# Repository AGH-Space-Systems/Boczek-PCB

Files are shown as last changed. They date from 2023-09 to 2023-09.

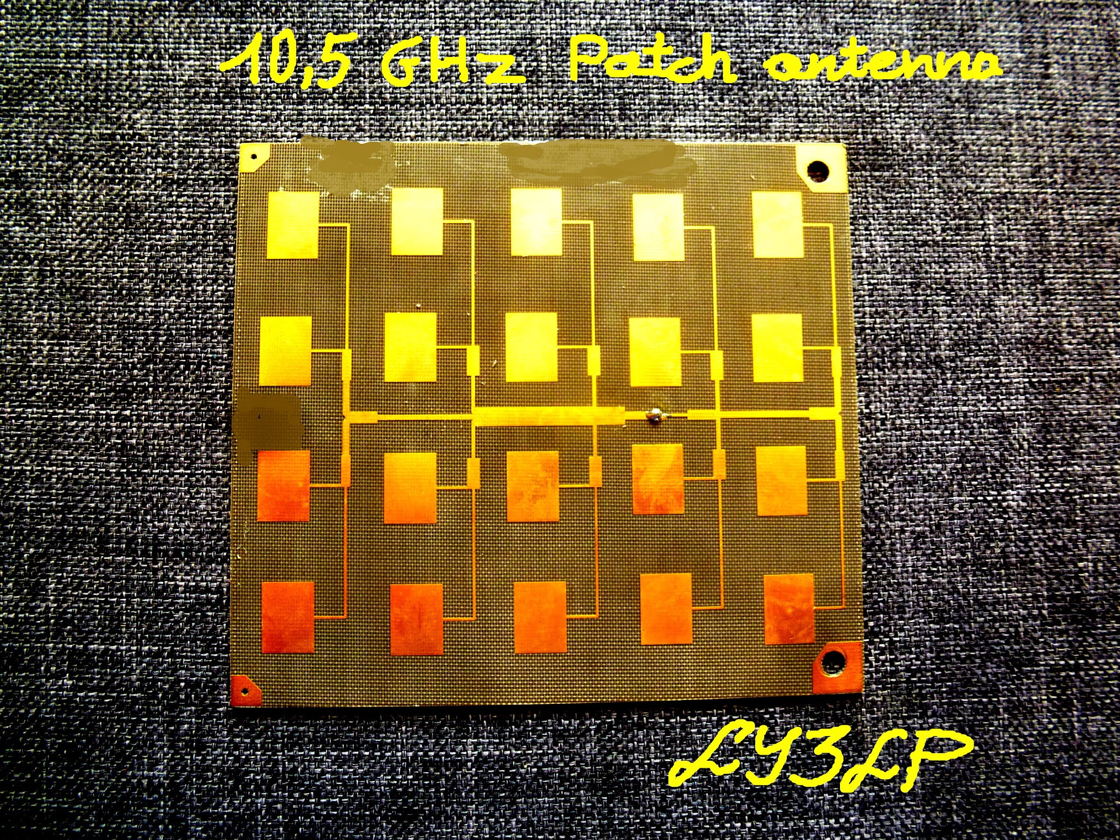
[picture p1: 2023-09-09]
ww.JPG

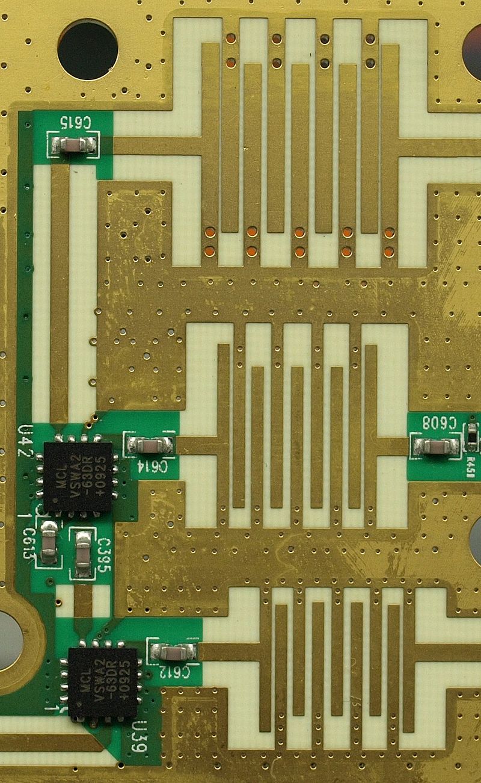
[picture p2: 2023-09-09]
Interdigital_Filter.jpg

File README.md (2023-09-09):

# Boczek-PCB
 5.8 GHz 1 W radio beacon that fits on a Li-Ion battery holder
Place libaries from "project specific libaries" in your libaries folder.
AlexRF has the filter, SamacSys_Parts the ICs.

RF PA:
https://www.mouser.pl/ProductDetail/Qorvo/RFPA5542BTR13?qs=u4fy%2FsgLU9OIcUWfOD%252Bf6g%3D%3D

3.3V LDO
https://www.mouser.pl/ProductDetail/Microchip-Technology/MIC94310-SYM5-TR?qs=U6T8BxXiZAWNaMNWfdoYvQ%3D%3D

2.2 2.5 75 3.2 × 2.5 × 1.2 HMME32251B--2R2MS CYNTEC
Coils
Have to handle 2.5A of peak switch current!
https://www.mouser.pl/ProductDetail/Laird-Performance-Materials/TYS40304R7M-10?qs=cCJXSq33DME5rIwYhom2LA%3D%3D

https://www.mouser.pl/datasheet/2/597/lps4018-270702.pdf

PCB (very important for the stripline filter to work!)
JLC04161H-7628 Stackup

BOM comming soon...

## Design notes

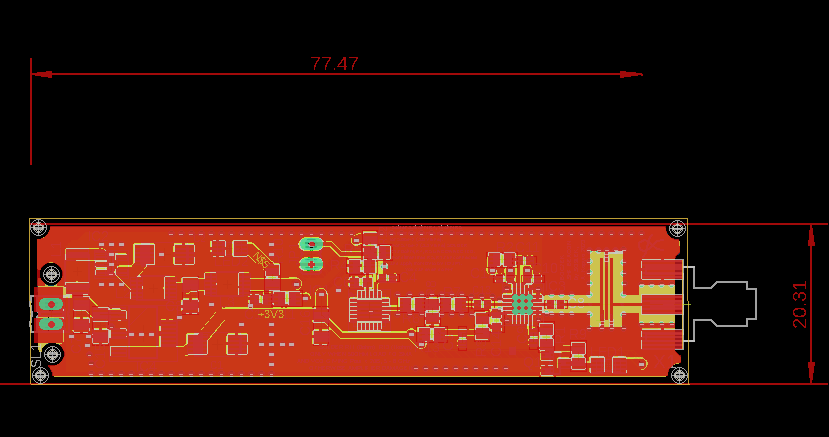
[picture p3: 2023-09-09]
board.png

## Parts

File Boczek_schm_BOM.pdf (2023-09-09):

Boczek_schm_BOM

Strona 1

Order QTY | Board QTY | Order Sub-total | Unit Price | Part | Value
10 | 1 | 26,00 zł | 2,60 zł | C1 | 4.7uF 25V 2 ohms ESR (ok enough?)
10 | 1 | 18,80 zł | 1,88 zł | C2 | 22uF 16V 1 ohm ESR (ok?)
10 | 1 | 2,80 zł | 0,28 zł | C3 | 47nF
20 | 4 | 7,04 zł | 0,35 zł | C4 C8 C9 C13 | 10pF
10 | 3 | 5,87 zł | 0,59 zł | C6 C14 C17 | 1nF
10 | 3 | 2,85 zł | 0,29 zł | C7 C15 C16 | 100nF
10 | 4 | 4,45 zł | 0,45 zł | C5 C10 C11 C12 | 2.2uF
2 | 1 | 187,08 zł | 93,54 zł | IC1 | HMC431LP4ETR
4 | 1 | 8,32 zł | 2,08 zł | IC2 | TPS613222ADBVR
3 | 1 | 43,26 zł | 14,42 zł | IC3 | RFPA5542BTR13
2 | 1 | 7,28 zł | 3,64 zł | IC4 | MCP1826S-3302E_DB
0 | 1 | 0,00 zł | 0,00 zł | JP1
10 | 1 | 20,40 zł | 2,04 zł | L1 | 2.2uH
10 | 2 | 20,40 zł | 2,04 zł | L2 L3 | 4.7uH
4 | 1 | 5,28 zł | 1,32 zł | LED1 | Amber 20mA
4 | 1 | 3,68 zł | 0,92 zł | LED2 | Green 20mA
5 | 1 | 3,41 zł | 0,68 zł | Q1 | BC847A
10 | 1 | 0,67 zł | 0,07 zł | R1 | 10k
20 | 3 | 1,60 zł | 0,08 zł | R2 R11 R12 | 0
20 | 4 | 1,34 zł | 0,07 zł | R3 R5 R10 R13 | 1k
10 | 1 | 0,40 zł | 0,04 zł | R4 | 3.3k*
10 | 1 | 0,40 zł | 0,04 zł | R6 R7 | 10
10 | 1 | 0,40 zł | 0,04 zł | R8 | 100
10 | 1 | 0,40 zł | 0,04 zł | R9 | 100k
2 | 1 | 22,34 zł | 11,17 zł | SL1 | please use 3500 mAh batts If you want 4h battery life
2 | 1 | 19,14 zł | 9,57 zł | X1 | 50 ohm SMA female pcb edge mount
| | 0,00 zł
2 | 1 | 60,00 zł | 30,00 zł | | 1.6 mm thickness
473,61 zł | = | PLN
for | 2 | devices | plus shipping
for | 1 | device: | 236,80 zł
| Gross: Total

waga | 50g | 0,05 | 4 736,09 zł /kg

Device | Package
CPOL-EUSMCE | SMC_C
CPOL-EUSMCE | SMC_C
C-EUC1206 | C1206
C-EUC0603 | C0603
C-EUC0603 | C0603
C-EUC1206 | C1206
C-EUC0402 | C0402
HMC431LP4ETR | QFN50P400X400X100-25N
TPS613222ADBVR | SOT95P280X145-5N
RFPA5542BTR13 | QFN50P400X400X85-21N
MCP1826S-3302E_DB | SOT230P700X180-4N
JP1E | JP1
SM-NE45 | SM-NE45
Converter Power Inductor | 4mm x 3mm x 4mm
LEDSMT1206 | 1206
LEDSMT1206 | 1206
BC847 | SOT23
R-EU_R0805 | R0805
R-EU_R0805 | R0805
R-EU_R0805 | R0805
R-EU_R0805 | R0805
R-EU_R0805 | R0805
R-EU_R0805 | R0805
R-EU_R0805 | R0805
18650 holder
SMA-142-0701-871/876 | CON-SMA-EDGE
JLC04161H-7628 Stackup | PCB

Description | MANUFACTURER_NAME
POLARIZED CAPACITOR, European symbol | Vishay / Sprauge
POLARIZED CAPACITOR, European symbol | KYOCERA AVX
CAPACITOR, European symbol | KEMET
CAPACITOR, European symbol | Walsin
CAPACITOR, European symbol | Wurth Elektronik
CAPACITOR, European symbol | KYOCERA AVX
CAPACITOR, European symbol | YAGEO
VCO Oscillators VCO SMT w/Buffer amp, 5.5 – 6.1 GHz | Analog Devices
6-uA Quiescent Current, 1.8-A Switch Current Boost Converter | Texas Instruments
RF Amplifier 5GHZ Discrete PA | Qorvo
LDO Regulator 1A 3.3V SOT223-3 MCP1826S-3302E/DB, Low Dropout Microchip
JUMPER
INDUCTOR | Bourns
INDUCTOR | Laird Performance Materials
LED | Lite-On
LED | Wurth Elektronik
NPN TRANSISTOR | onsemi
RESISTOR, European symbol | YAGEO
RESISTOR, European symbol | Vishay / Dale
RESISTOR, European symbol | Walsin
RESISTOR, European symbol | Walsin
RESISTOR, European symbol | Walsin
RESISTOR, European symbol | Walsin
RESISTOR, European symbol | Walsin
Cylindrical Battery Contacts, Clips, Holders & Springs 18650 P | Keystone Electronics
SMA 50 Ohm End Launch Jack Receptacle - Round Contact | 114SMAFRA.YC

Board Stackup

MANUFACTURER_PART_NUMBER | MOUSER_PART_NUMBER
293D475X9025C2TE3 | 74-293D475X9025C2TE3
TAJC226M016RNJ | 581-TAJC226M016R
C1206C473K5RACTU | 80-C1206C473K5R
RF15N100J250CT | 791-RF15N100J250CT
885382206005 | 710-885382206005
KGM31BR71H104KT | 581-KGM31BR71H104KT
CC0402KRX5R8B225 | 603-CC0402KRX5R8B225
HMC431LP4ETR | 584-HMC431LP4ETR
TPS613222ADBVR | 595-TPS613222ADBVR
RFPA5542BTR13 | 772-RFPA5542BTR13
MCP1826S-3302E/DB | 579-MCP1826S-3302EDB
SRP3212A-2R2M | 652-SRP3212A-2R2M
TYS40304R7M-10 | 875-TYS40304R7M-10
LTST-C150AKT | 859-LTST-C150AKT
150120VS75000 | 710-150120VS75000
BC847AWT1G | 863-BC847AWT1G
AC0805JR-0710KL | 603-AC0805JR-0710KL
CRCW08050000Z0EAC | 71-CRCW08050000Z0EAC
WR08X1001FTL | 791-WR08X1001FTL
WR08X332JTL | 791-WR08X332JTL
WR08X100JTL | 791-WR08X100JTL
WR08X101JTL | 791-WR08X101JTL
791-WR08X104JTL | WR08X104JTL
1043 534-1043
CON-SMA-EDGE | 114SMAFRA.YC

`

https://www.mouser.co.uk/ProductDetail/Qorvo/RFPA5542BTR13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 -

https://www.mouser.pl/ProductDetail/Vishay-Sprague/293D475X9025C2TE3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

https://www.mouser.pl/ProductDetail/Walsin/RF15N100J250CT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

https://www.mouser.pl/ProductDetail/Wurth-Elektronik/885382206005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

https://www.mouser.pl/ProductDetail/KYOCERA-AVX/KGM31BR71H104KT?qs=Jm2GQyTW%2FbjhvPjYj1wIYA%3D%3D

https://www.mouser.pl/ProductDetail/YAGEO/CC0402KRX5R8BB225?qs=0lQeLiL1qyYyJhAVzXjbiw%3D%3D

https://www.mouser.pl/ProductDetail/Analog-Devices/HMC431LP4ETR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

https://www.mouser.pl/ProductDetail/Bourns/SRP3212A-2R2M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

https://www.mouser.pl/ProductDetail/Vishay-Dale/CRCW08050000Z0EAC?qs=E3Y5ESvWgWMnvHb9ZvShmA%3D%3D

https://www.mouser.pl/ProductDetail/Walsin/WR08X1001FTL?qs=1w%252B2sDiFrrG9QUazmDfw8A%3D%3D

https://www.mouser.pl/ProductDetail/Walsin/WR08X332-JTL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

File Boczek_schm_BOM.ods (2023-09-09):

Order QTY | Board QTY | Order Sub-total | Unit Price | Part | Value | Device | Package | Description | MANUFACTURER_NAME | MANUFACTURER_PART_NUMBER | MOUSER_PART_NUMBER | `
10 | 1 | 26,00 zł | 2,60 zł | C1 | 4.7uF 25V 2 ohms ESR (ok enough?) | CPOL-EUSMCE | SMC_C | POLARIZED CAPACITOR, European symbol | Vishay / Sprauge | 293D475X9025C2TE3 | 74-293D475X9025C2TE3 | https://www.mouser.pl/ProductDetail/Vishay-Sprague/293D475X9025C2TE3
10 | 1 | 18,80 zł | 1,88 zł | C2 | 22uF 16V 1 ohm ESR (ok?) | CPOL-EUSMCE | SMC_C | POLARIZED CAPACITOR, European symbol | KYOCERA AVX | TAJC226M016RNJ | 581-TAJC226M016R | https://www.mouser.pl/ProductDetail/KYOCERA-AVX/TAJC226M016RNJ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
10 | 1 | 2,80 zł | 0,28 zł | C3 | 47nF | C-EUC1206 | C1206 | CAPACITOR, European symbol | KEMET | C1206C473K5RACTU | 80-C1206C473K5R | https://www.mouser.pl/ProductDetail/KEMET/C1206C473K5RACTU
20 | 4 | 7,04 zł | 0,35 zł | C4 C8 C9 C13 | 10pF | C-EUC0603 | C0603 | CAPACITOR, European symbol | Walsin | RF15N100J250CT | 791-RF15N100J250CT | https://www.mouser.pl/ProductDetail/Walsin/RF15N100J250CT
10 | 3 | 5,87 zł | 0,59 zł | C6 C14 C17 | 1nF | C-EUC0603 | C0603 | CAPACITOR, European symbol | Wurth Elektronik | 885382206005 | 710-885382206005 | https://www.mouser.pl/ProductDetail/Wurth-Elektronik/885382206005
10 | 3 | 2,85 zł | 0,29 zł | C7 C15 C16 | 100nF | C-EUC1206 | C1206 | CAPACITOR, European symbol | KYOCERA AVX | KGM31BR71H104KT | 581-KGM31BR71H104KT | https://www.mouser.pl/ProductDetail/KYOCERA-AVX/KGM31BR71H104KT?qs=Jm2GQyTW%2FbjhvPjYj1wIYA%3D%3D
10 | 4 | 4,45 zł | 0,45 zł | C5 C10 C11 C12 | 2.2uF | C-EUC0402 | C0402 | CAPACITOR, European symbol | YAGEO | CC0402KRX5R8B225 | 603-CC0402KRX5R8B225 | https://www.mouser.pl/ProductDetail/YAGEO/CC0402KRX5R8BB225?qs=0lQeLiL1qyYyJhAVzXjbiw%3D%3D
2 | 1 | 187,08 zł | 93,54 zł | IC1 | HMC431LP4ETR | HMC431LP4ETR | QFN50P400X400X100-25N | VCO Oscillators VCO SMT w/Buffer amp, 5.5 – 6.1 GHz | Analog Devices | HMC431LP4ETR | 584-HMC431LP4ETR | https://www.mouser.pl/ProductDetail/Analog-Devices/HMC431LP4ETR?qs=pceeu5JH%2FH%2FRfErFx7EAsA%3D%3D
4 | 1 | 8,32 zł | 2,08 zł | IC2 | TPS613222ADBVR | TPS613222ADBVR | SOT95P280X145-5N | 6-uA Quiescent Current, 1.8-A Switch Current Boost Converter | Texas Instruments | TPS613222ADBVR | 595-TPS613222ADBVR | https://www.mouser.pl/ProductDetail/Texas-Instruments/TPS613222ADBVR?qs=W0yvOO0ixfE4d69WXsn8NQ%3D%3D
3 | 1 | 43,26 zł | 14,42 zł | IC3 | RFPA5542BTR13 | RFPA5542BTR13 | QFN50P400X400X85-21N | RF Amplifier 5GHZ Discrete PA | Qorvo | RFPA5542BTR13 | 772-RFPA5542BTR13 | https://www.mouser.co.uk/ProductDetail/Qorvo/RFPA5542BTR13?qs=u4fy%2FsgLU9OIcUWfOD%252Bf6g%3D%3D
2 | 1 | 7,28 zł | 3,64 zł | IC4 | MCP1826S-3302E_DB | MCP1826S-3302E_DB | SOT230P700X180-4N | LDO Regulator 1A 3.3V SOT223-3 MCP1826S-3302E/DB, Low Dropout Voltage Regulator, 1A, 3.3 V +/-2%, 2.3 6 Vin, 4-Pin SOT-223 | Microchip | MCP1826S-3302E/DB | 579-MCP1826S-3302EDB | https://www.mouser.co.uk/ProductDetail/Microchip-Technology-Atmel/MCP1826S-3302E-DB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
0 | 1 | 0,00 zł | 0,00 zł | JP1 |  | JP1E | JP1 | JUMPER |  |  |  | -
10 | 1 | 20,40 zł | 2,04 zł | L1 | 2.2uH | SM-NE45 | SM-NE45 | INDUCTOR | Bourns | SRP3212A-2R2M | 652-SRP3212A-2R2M | https://www.mouser.pl/ProductDetail/Bourns/SRP3212A-2R2M?qs=t7xnP681wgXn6xyeAWQUgg%3D%3D
10 | 2 | 20,40 zł | 2,04 zł | L2 L3 | 4.7uH | Converter Power Inductor | 4mm x 3mm x 4mm | INDUCTOR | Laird Performance Materials | TYS40304R7M-10 | 875-TYS40304R7M-10 | https://www.mouser.pl/ProductDetail/Laird-Performance-Materials/TYS40304R7M-10?qs=cCJXSq33DME5rIwYhom2LA%3D%3D
4 | 1 | 5,28 zł | 1,32 zł | LED1 | Amber 20mA | LEDSMT1206 | 1206 | LED | Lite-On | LTST-C150AKT | 859-LTST-C150AKT | https://www.mouser.pl/ProductDetail/Lite-On/LTST-C150AKT?qs=osRiLXwIJd0WBpdBnGWjYQ%3D%3D
4 | 1 | 3,68 zł | 0,92 zł | LED2 | Green 20mA | LEDSMT1206 | 1206 | LED | Wurth Elektronik | 150120VS75000 | 710-150120VS75000 | https://www.mouser.pl/ProductDetail/Wurth-Elektronik/150120VS75000?qs=LlUlMxKIyB19Jz1m%2F52oVA%3D%3D
5 | 1 | 3,41 zł | 0,68 zł | Q1 | BC847A | BC847 | SOT23 | NPN TRANSISTOR | onsemi | BC847AWT1G | 863-BC847AWT1G | https://www.mouser.pl/ProductDetail/onsemi/BC847AWT1G?qs=vNc2DXHODiLhGeJiJa%252BVKw%3D%3D
10 | 1 | 0,67 zł | 0,07 zł | R1 | 10k | R-EU_R0805 | R0805 | RESISTOR, European symbol | YAGEO | AC0805JR-0710KL | 603-AC0805JR-0710KL | https://www.mouser.pl/ProductDetail/YAGEO/AC0805JR-0710KL?qs=ygRr%2Ftkhtes%252BG%252B8d7tcP9w%3D%3D
20 | 3 | 1,60 zł | 0,08 zł | R2 R11 R12 | 0 | R-EU_R0805 | R0805 | RESISTOR, European symbol | Vishay / Dale | CRCW08050000Z0EAC | 71-CRCW08050000Z0EAC | https://www.mouser.pl/ProductDetail/Vishay-Dale/CRCW08050000Z0EAC?qs=E3Y5ESvWgWMnvHb9ZvShmA%3D%3D
20 | 4 | 1,34 zł | 0,07 zł | R3 R5 R10 R13 | 1k | R-EU_R0805 | R0805 | RESISTOR, European symbol | Walsin | WR08X1001FTL | 791-WR08X1001FTL | https://www.mouser.pl/ProductDetail/Walsin/WR08X1001FTL?qs=1w%252B2sDiFrrG9QUazmDfw8A%3D%3D
10 | 1 | 0,40 zł | 0,04 zł | R4 | 3.3k* | R-EU_R0805 | R0805 | RESISTOR, European symbol | Walsin | WR08X332JTL | 791-WR08X332JTL | https://www.mouser.pl/ProductDetail/Walsin/WR08X332-JTL?qs=1w%252B2sDiFrrFmEm9bf8ikYw%3D%3D
10 | 1 | 0,40 zł | 0,04 zł | R6 R7 | 10 | R-EU_R0805 | R0805 | RESISTOR, European symbol | Walsin | WR08X100JTL | 791-WR08X100JTL | https://www.mouser.pl/ProductDetail/Walsin/WR08X100-JTL?qs=1w%252B2sDiFrrH8fEn7ox81PA%3D%3D
10 | 1 | 0,40 zł | 0,04 zł | R8 | 100 | R-EU_R0805 | R0805 | RESISTOR, European symbol | Walsin | WR08X101JTL | 791-WR08X101JTL | https://www.mouser.pl/ProductDetail/Walsin/WR08X101-JTL?qs=1w%252B2sDiFrrFGOedZ9nmRhw%3D%3D
10 | 1 | 0,40 zł | 0,04 zł | R9 | 100k | R-EU_R0805 | R0805 | RESISTOR, European symbol | Walsin | 791-WR08X104JTL | WR08X104JTL | https://www.mouser.pl/ProductDetail/Walsin/WR08X104-JTL?qs=1w%252B2sDiFrrHxNcDKjG04Tg%3D%3D
2 | 1 | 22,34 zł | 11,17 zł | SL1 | please use 3500 mAh batts If you want 4h battery life | 18650 holder |  | Cylindrical Battery Contacts, Clips, Holders & Springs 18650 PCB PLASTIC BATT HLDR THM 1 CELL | Keystone Electronics | 1043 | 534-1043 | https://www.mouser.pl/ProductDetail/Keystone-Electronics/1043?qs=%2F7TOpeL5Mz6j%2FnxeOA1rsg%3D%3D
2 | 1 | 19,14 zł | 9,57 zł | X1 | 50 ohm SMA female pcb edge mount | SMA-142-0701-871/876 | CON-SMA-EDGE | SMA 50 Ohm End Launch Jack Receptacle - Round Contact | 114SMAFRA.YC | CON-SMA-EDGE | 114SMAFRA.YC | https://www.mouser.pl/ProductDetail/RF-Solutions/CON-SMA-EDGE?qs=UkDUCjYnTB3wOPRCaplkvw%3D%3D
 |  | 0,00 zł
2 | 1 | 60,00 zł | 30,00 zł |  | 1.6 mm thickness | JLC04161H-7628 Stackup | PCB | Board Stackup
 | Gross: Total | 473,61 zł | = | PLN
for | 2 | devices | plus shipping
for | 1 | device: | 236,80 zł
waga | 50g | 0,05 | 4 736,09 zł | /kg

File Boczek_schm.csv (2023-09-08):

Qty | Value | Device | Package | Parts | Description | DESCRIPTION | HEIGHT | MANUFACTURER_NAME | MANUFACTURER_PART_NUMBER | MF | MOUSER_PART_NUMBER | MOUSER_PRICE-STOCK | MPN | OC_FARNELL | OC_NEWARK | POPULARITY | SPICEPREFIX
1 |  | JP1E | JP1 | JP1 | JUMPER |  |  |  |  |  |  |  |  |  |  | 61
2 |  | LEDSMT1206 | 1206 | LED1, LED2 | LED |  |  |  |  |  |  |  |  |  |  | 20
1 |  | M02 | 02P | SL1 | AMP QUICK CONNECTOR |  |  |  |  |  |  |  |  | unknown | unknown | 33
3 | 0 | R-EU_R0603 | R0603 | R2, R11, R12 | RESISTOR, European symbol |  |  |  |  |  |  |  |  |  |  | 70 | R
2 | 10 | R-EU_R0603 | R0603 | R6, R7 | RESISTOR, European symbol
1 | 100 | R-EU_R0603 | R0603 | R8 | RESISTOR, European symbol
1 | 100k | R-EU_R0603 | R0603 | R9 | RESISTOR, European symbol
3 | 100nF | C-EUC1206 | C1206 | C7, C15, C16 | CAPACITOR, European symbol |  |  |  |  |  |  |  |  |  |  | 54 | C
1 | 10k | R-EU_R0603 | R0603 | R1 | RESISTOR, European symbol |  |  |  |  |  |  |  |  |  |  | 70 | R
3 | 10pF | C-EUC0402 | C0402 | C8, C9, C13 | CAPACITOR, European symbol |  |  |  |  |  |  |  |  |  |  | 18 | C
1 | 10pF | C-EUC0603 | C0603 | C4 | CAPACITOR, European symbol |  |  |  |  |  |  |  |  |  |  | 73 | C
3 | 1k | R-EU_R0603 | R0603 | R3, R10, R13 | RESISTOR, European symbol |  |  |  |  |  |  |  |  |  |  | 70 | R
1 | 1k | R-EU_R0603 | R0603 | R5 | RESISTOR, European symbol
3 | 1nF | C-EUC0402 | C0402 | C6, C14, C17 | CAPACITOR, European symbol |  |  |  |  |  |  |  |  |  |  | 18 | C
1 | 1uF | C-EUC1206 | C1206 | C5 | CAPACITOR, European symbol |  |  |  |  |  |  |  |  |  |  | 54 | C
3 | 2.2uF | C-EUC0402 | C0402 | C10, C11, C12 | CAPACITOR, European symbol |  |  |  |  |  |  |  |  |  |  | 18 | C
1 | 2.2uH | SM-NE45 | SM-NE45 | L1 | INDUCTOR |  |  |  |  |  |  |  |  | unknown | unknown | 0
1 | 22uF | CPOL-EUSMCE | SMC_E | C2 | POLARIZED CAPACITOR, European symbol |  |  |  |  |  |  |  |  |  |  | 1 | C
1 | 3.3k* | R-EU_R0603 | R0603 | R4 | RESISTOR, European symbol
1 | 4.7uF | CPOL-EUSMCE | SMC_E | C1 | POLARIZED CAPACITOR, European symbol |  |  |  |  |  |  |  |  |  |  | 1 | C
1 | 4.7uH | SM-NE45 | SM-NE45 | L4 | INDUCTOR |  |  |  |  |  |  |  |  | unknown | unknown | 0
1 | 4.7uH | SM-NE45 | SM-NE45 | L2 | INDUCTOR |  |  |  |  |  |  |  |  | unknown | unknown | 0 | L
1 | 47nF | C-EUC1206 | C1206 | C3 | CAPACITOR, European symbol |  |  |  |  |  |  |  |  |  |  | 54 | C
1 | BC847 | BC847 | SOT23 | Q1 | NPN TRANSISTOR |  |  |  |  |  |  |  |  |  |  | 5
1 | HMC430LP4ETR | HMC430LP4ETR | QFN50P400X400X100-25N | IC1 | VCO Oscillators VCO SMT w/Buffer amp, 5.0 - 5.5 GHz | VCO Oscillators VCO SMT w/Buffer amp, 5.0 - 5.5 GHz | 1mm | Analog Devices | HMC431LP4ETR |  | 584-HMC430LP4ETR | https://www.mouser.co.uk/ProductDetail/Analog-Devices/HMC430LP4ETR?qs=pceeu5JH%2FH8gg6v6ve1tvQ%3D%3D
1 | INTERDIGITAL_FILTER_3RD_ORDER | INTERDIGITAL_FILTER_3RD_ORDER | JLC7628_5000_6000_3RDORDER_FILTER | U$1 | JLC04161H-7628 Stackup
1 | MCP1826S-3302E_DB | MCP1826S-3302E_DB | SOT230P700X180-4N | IC4 | LDO Regulator 1A 3.3V SOT223-3 MCP1826S-3302E/DB, Low Dropout Voltage Regulator, 1A, 3.3 V +/-2%, 2.3 6 Vin, 4-Pin SOT-223 | LDO Regulator 1A 3.3V SOT223-3 MCP1826S-3302E/DB, Low Dropout Voltage Regulator, 1A, 3.3 V +/-2%, 2.3 6 Vin, 4-Pin SOT-223 | 1.8mm | Microchip | MCP1826S-3302E/DB |  | 579-MCP1826S-3302EDB | https://www.mouser.co.uk/ProductDetail/Microchip-Technology-Atmel/MCP1826S-3302E-DB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
1 | RFPA5542BTR13 | RFPA5542BTR13 | QFN50P400X400X85-21N | IC3 | RF Amplifier 5GHZ Discrete PA | RF Amplifier 5GHZ Discrete PA | 0.85mm | Qorvo | RFPA5542BTR13 |  | 772-RFPA5542BTR13 | https://www.mouser.co.uk/ProductDetail/Qorvo/RFPA5542BTR13?qs=u4fy%2FsgLU9OIcUWfOD%252Bf6g%3D%3D
1 | SMA-142-0701-871/876 | SMA-142-0701-871/876 | J502-ND-142-0701-871/876 | X1 | SMA 50 Ohm End Launch Jack Receptacle - Round Contact |  |  |  |  | JOHNSON COMPONENTS |  |  | 142-0701-871 | 1339835 | 91B6105 | 1
1 | TPS613222ADBVR | TPS613222ADBVR | SOT95P280X145-5N | IC2 | 6-uA Quiescent Current, 1.8-A Switch Current Boost Converter | 6-uA Quiescent Current, 1.8-A Switch Current Boost Converter | 1.45mm | Texas Instruments | TPS613222ADBVR |  | 595-TPS613222ADBVR | https://www.mouser.co.uk/ProductDetail/Texas-Instruments/TPS613222ADBVR?qs=W0yvOO0ixfE4d69WXsn8NQ%3D%3D

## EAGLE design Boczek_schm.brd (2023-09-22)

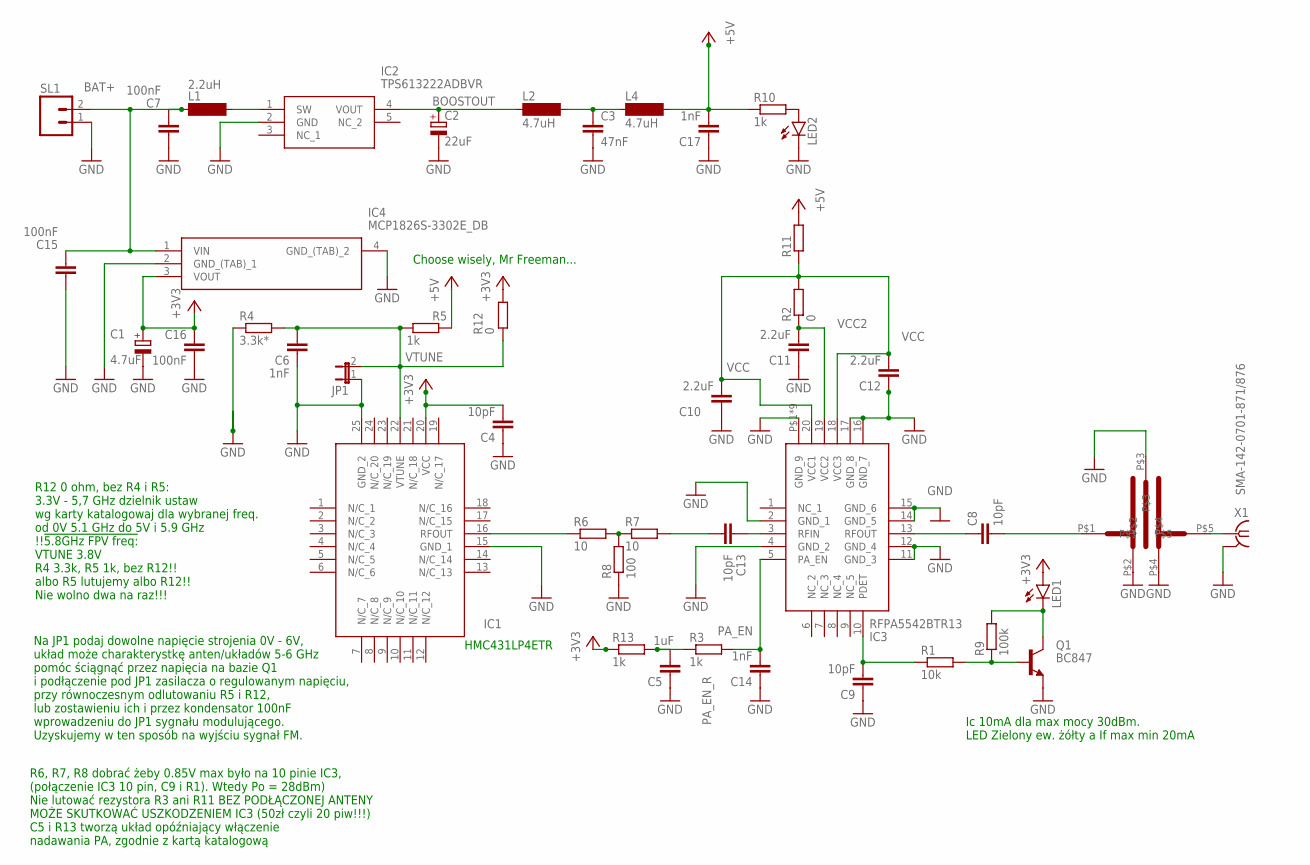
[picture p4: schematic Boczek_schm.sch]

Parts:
C1: 4.7uF; SMC_E
C2: 22uF; SMC_E
C3: 47nF; C1206
C4: 10pF; C0603
C5: 1uF; C1206
C6, C14, C17: 1nF; C0402
C7, C15, C16: 100nF; C1206
C8, C9, C13: 10pF; C0402
C10, C11, C12: 2.2uF; C0402
IC1: HMC430LP4ETR; QFN50P400X400X100-25N; MANUFACTURER_PART_NUMBER HMC431LP4ETR
IC2: TPS613222ADBVR; SOT95P280X145-5N
IC3: RFPA5542BTR13; QFN50P400X400X85-21N
IC4: MCP1826S-3302E_DB; SOT230P700X180-4N
JP1: JP1E; JP1
L1: 2.2uH; SM-NE45
L2, L4: 4.7uH; SM-NE45
LED1, LED2: LEDSMT1206; 1206
Q1: BC847; SOT23
R1: 10k; R0603
R2, R11, R12: 0; R0603
R3, R5, R10, R13: 1k; R0603
R4: 3.3k*; R0603
R6, R7: 10; R0603
R8: 100; R0603
R9: 100k; R0603
SL1: M02; 02P
U$1: INTERDIGITAL_FILTER_3RD_ORDER; JLC7628_5000_6000_3RDORDER_FILTER
X1: SMA-142-0701-871/876; J502-ND-142-0701-871/876

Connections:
+3V3: C1.+, C4.2, C16.2, IC1.20 (VCC), IC4.3 (VOUT), LED1.A, R12.2, R13.1
+5V: C17.2, L4.2, R5.2, R10.1, R11.2; also elsewhere on the board
BAT+: C7.2, C15.2, IC4.1 (VIN), L1.1, SL1.2
BOOSTOUT: C2.+, IC2.4 (VOUT), L2.1
GND: C1.-, C2.-, C3.2, C4.1, C5.1, C6.1, C7.1, C9.1, C10.1, C11.1, C12.1, C14.1, C15.1, C16.1, C17.1, IC1.15 (GND_1), IC1.25 (GND_2), IC2.2 (GND), IC3.2 (GND_1), IC3.4 (GND_2), IC3.11 (GND_3), IC3.12 (GND_4), IC3.14 (GND_5), IC3.15 (GND_6), IC3.16 (GND_7), IC3.17 (GND_8), IC3.P$1 (GND_9), IC3.P$2 (GND_9), IC3.P$3 (GND_9), IC3.P$4 (GND_9), IC3.P$5 (GND_9), IC3.P$6 (GND_9), IC3.P$7 (GND_9), IC3.P$8 (GND_9), IC3.P$9 (GND_9), IC4.2 (GND_(TAB)_1), IC4.4 (GND_(TAB)_2), JP1.1, LED2.C, Q1.2 (E), R4.1, R8.1, SL1.1, U$1.P$2, U$1.P$3, U$1.P$4, X1.G@1 (2), X1.G@2 (2), X1.G@3 (2), X1.G@4 (2)
unnamed: U$1.P$5, X1.1
unnamed: IC1.16 (RFOUT), R6.1
unnamed: R6.2, R7.1, R8.2
unnamed: C13.1, IC3.3 (RFIN)
unnamed: LED2.A, R10.2
unnamed: C8.2, U$1.P$1
unnamed: IC2.1 (SW), L1.2
unnamed: C13.2, R7.2
unnamed: C9.2, IC3.10 (PDET), R1.1
unnamed: LED1.C, Q1.3 (C), R9.2
unnamed 15: C3.1, L2.2, L4.1; also elsewhere on the board
unnamed: Q1.1 (B), R1.2, R9.1
unnamed: C8.1, IC3.13 (RFOUT)
PA_EN: C14.2, IC3.5 (PA_EN), R3.2
PA_EN_R: C5.2, R3.1, R13.2
VCC: C10.2, C12.2, IC3.18 (VCC3), IC3.20 (VCC1), R2.2, R11.1
VCC2: C11.2, IC3.19 (VCC2), R2.1
VTUNE: C6.2, IC1.22 (VTUNE), JP1.2, R4.2, R5.1, R12.1

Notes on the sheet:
HMC431LP4ETR
Choose wisely, Mr Freeman...
R12 0 ohm, bez R4 i R5: 3.3V - 5,7 GHz dzielnik ustaw wg karty katalogowaj dla wybranej freq. od 0V 5.1 GHz do 5V i 5.9 GHz !!!5.8GHz FPV freq: VTUNE 3.8V R4 3.3k, R5 1k, bez R12!! albo R5 lutujemy albo R12!! Nie wolno dwa na raz!!!
Na JP1 podaj dowolne napięcie strojenia 0V - 6V, układ może charakterystkę anten/układów 5-6 GHz pomóc ściągnąć przez napięcia na bazie Q1 i podłączenie pod JP1 zasilacza o regulowanym napięciu, przy równoczesnym odlutowaniu R5 i R12, lub zostawieniu ich i przez kondensator 100nF wprowadzeniu do JP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
R6, R7, R8 dobrać żeby 0.85V max było na 10 pinie IC3, (połączenie IC3 10 pin, C9 i R1). Wtedy Po = 28dBm) Nie lutować rezystora R3 ani R11 BEZ PODŁĄCZONEJ ANTENY MOŻE SKUTKOWAĆ USZKODZENIEM IC3 (50zł czyli 20 piw!!!) C5 i R13 tworzą układ opóźniający włączenie nadawania PA, zgodnie z kartą katalog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
Ic 10mA dla max mocy 30dBm. LED Zielony ew. żółty a If max min 20mA

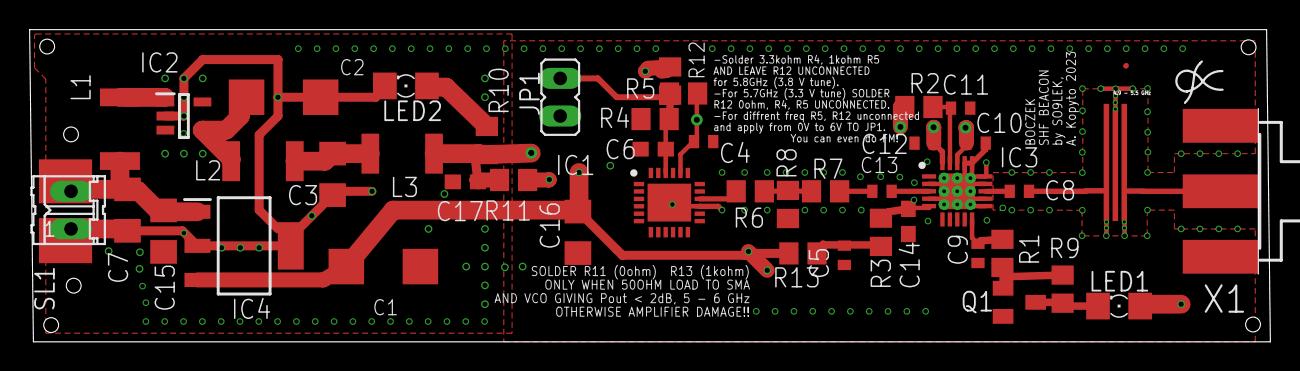
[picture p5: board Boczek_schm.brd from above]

Board: 4 copper layers, 83.7 x 21.1 mm, 44 parts (0 on the bottom side), 23 nets.

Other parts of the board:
L3: 4.7uH; SM-NE45

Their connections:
+5V: L3.2; also elsewhere on the board
unnamed 15: L3.1; also elsewhere on the board

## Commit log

2023-09-08 Removing unused files
    [Boczek_schm1.brd, Boczek_schm_BFRFLOOD.brd, Boczek_schm_BFRFLOOD.sch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]
2023-09-09 Grand update, BOM for two devices
    WE MAKING OUT OF BETA WITH THIS ONE 🗣🗣🗣🔥🔥🥶🥶
    -Completed BOM, board and schematic
    -Unified element usage (all resistors now 0803)
    -Rearanged the VCO tuning resistors, so that illegal combinations (R5 and R12)
    -Added startup and assembly instruction on the board and in the schematic (don't be scared, it's Polish)
    -redid the output filter to match the frequncy span. It's now 3 element and uses a different response curve, giving lower loss, about 1 dB in passband
    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
    [Boczek_schm_BOM.ods]
2023-09-22 Gerbers added (Final production commit???)
    Added gerbers, nothing else changed.
    [Boczek_schm.brd]
